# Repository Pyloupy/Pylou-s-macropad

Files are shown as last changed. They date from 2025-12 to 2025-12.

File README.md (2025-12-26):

# Pylou-s-macropad
A custom macropad for the awesome project hackpad! Using a screen 4 keys a knob and a bunch of LEDs, i'll try to develop a custom firmware with KMK to configure a bunch of things (that doesn't mean anything yet) from your PC!

## CAD
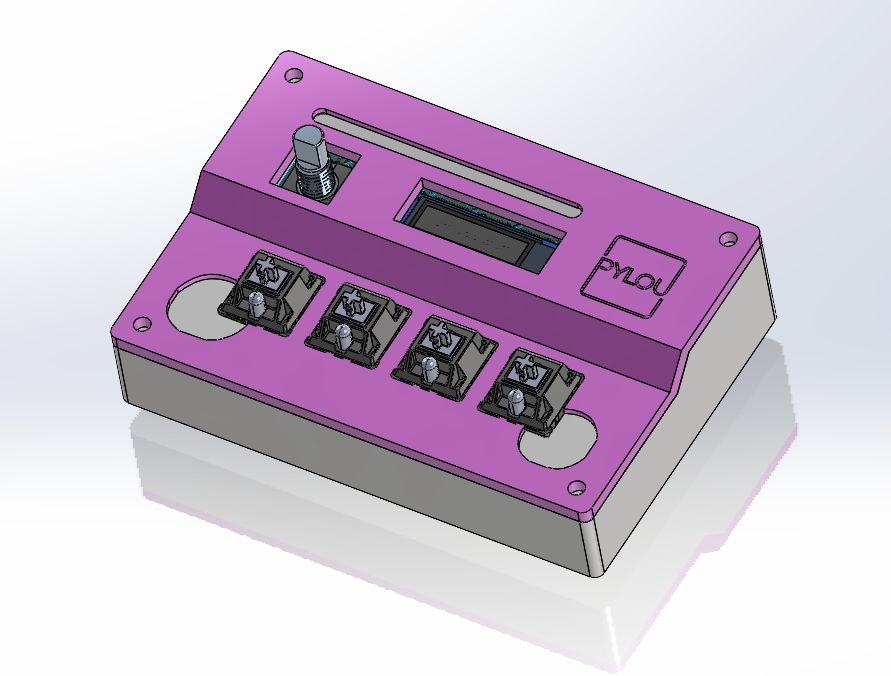
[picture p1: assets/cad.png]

My beautiful Case for this keyboard :). top and bot part fits together with simple M3 screws and heatset inserts and all 4 corners and one screw for the pcb. (I didn't add extra photos to show how it'll fit because its='s pretty self explanatory)

There's also diffuser that'll be simple 1-2mm plane of white PLA, they'll be glued to the top part!

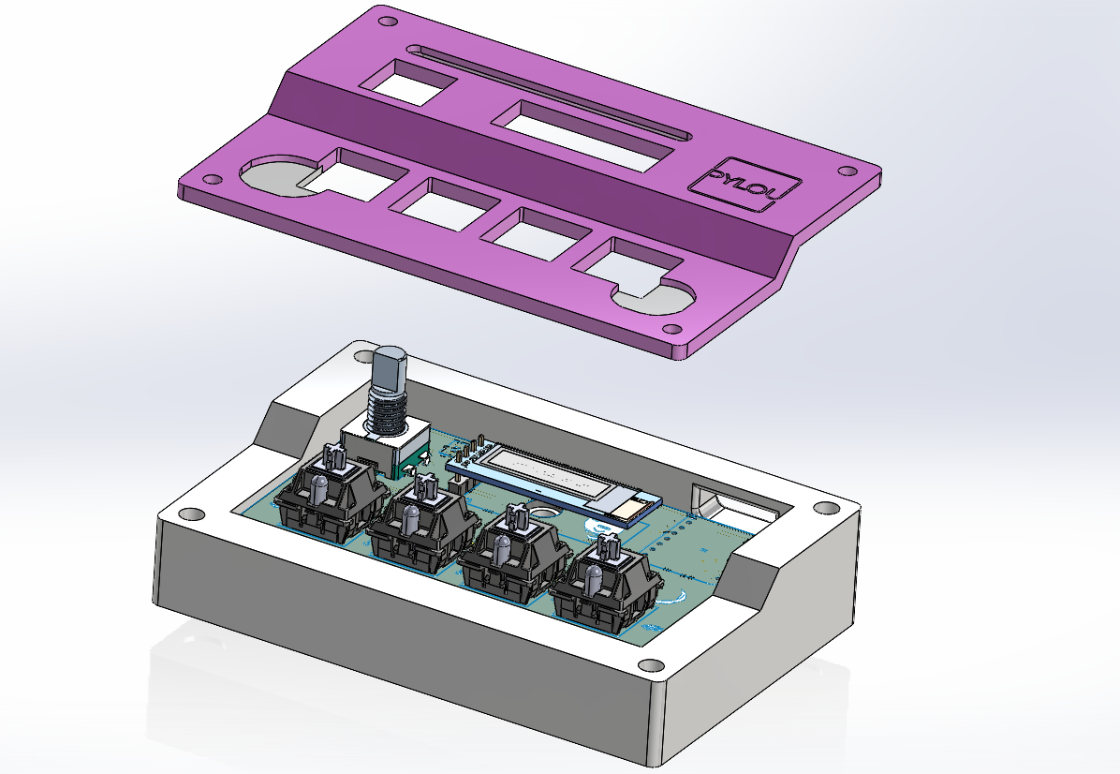
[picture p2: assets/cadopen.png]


Made with SOLIDWORKS (superior to Fusion360 :)) and it's the first time im designing a piece with it (in the past i was using blender for 3d printing ;-;), I hope it works!

## PCB
I used KiCad (for the first time) and i tried to make a compact and clean pcb with small reference and private jokes with my friends!

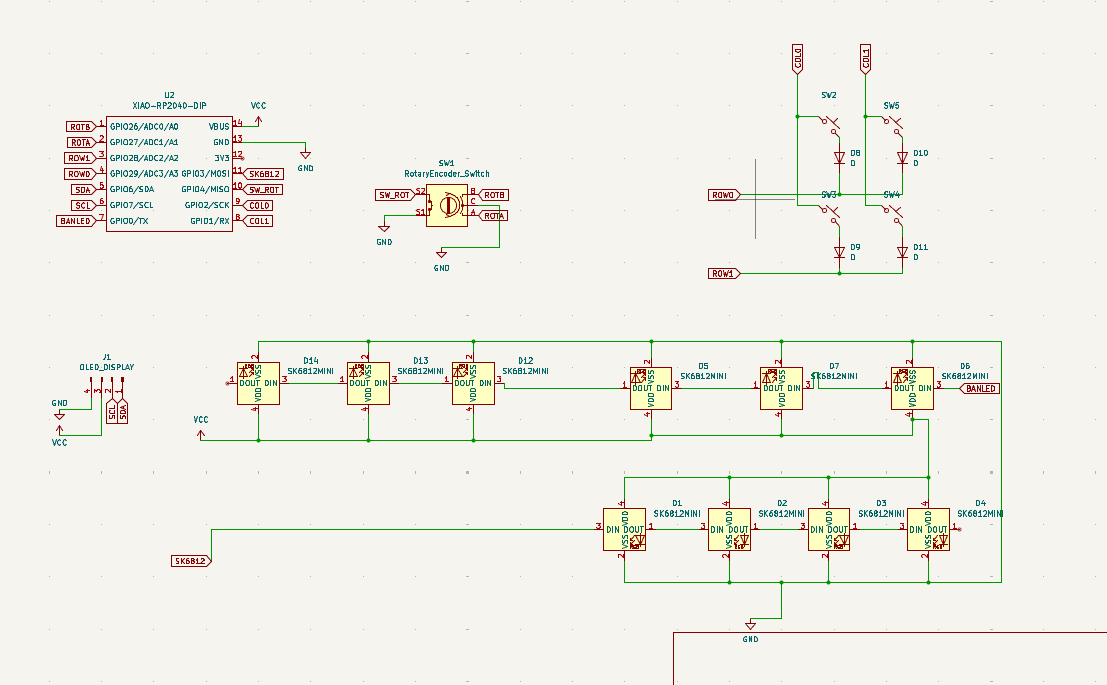
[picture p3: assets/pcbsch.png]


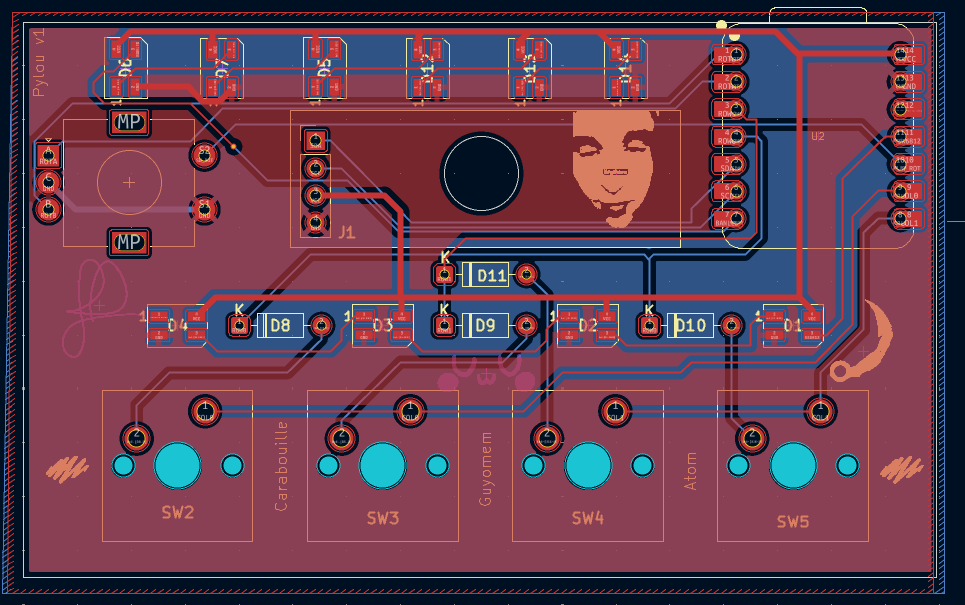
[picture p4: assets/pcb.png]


## Firmware
Made in KMK by reading docs, tutorials from [this guy](https://www.youtube.com/watch?v=PKTRkv8d0NU&list=PLtl-yze0Zzkm5n2ajJRUL48EyCyUgsXf6) (he's great) and a bit of gemini.

It's pretty simple for the moment, but i plan on addings multiples features to configure what keys does what (from your pc), change whats on the screen, show the time, rgb modes etc when i'll build the pad. I'll update the code when everything will be done! 

## BOM
Here's the list of parts for my project!

 - 1x Seeed XIAO RP2040
 - 4x Through-hole 1N4148 Diodes
 - 4x MX-Style switches
 - 1x EC11 Rotary encoders
 - 1x 0.91 inch OLED displays
 - 4x Blank DSA keycaps (White)
 - 10x SK6812 MINI-E LEDs
 - 5x M3x16mm screws
 - 5x M3x5mx4mm heatset inserts
 - 1x 3D printed case: top pink and the rest white

## Special Thanks!
My appreciation to the opheuspad project wich helped me many times! and to the hacklab community very responsive and kind!

PS: I'm french, so forgive me for any english syntax errors :)

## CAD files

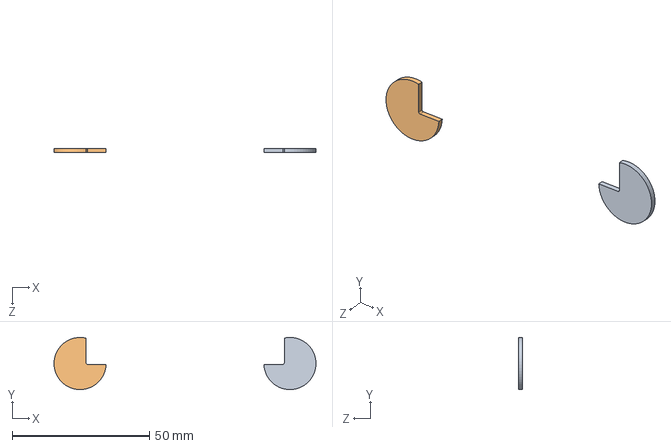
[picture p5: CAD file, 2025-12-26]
production/round diffuser near keys.STEP
95.5 x 19.0 x 1.60 mm

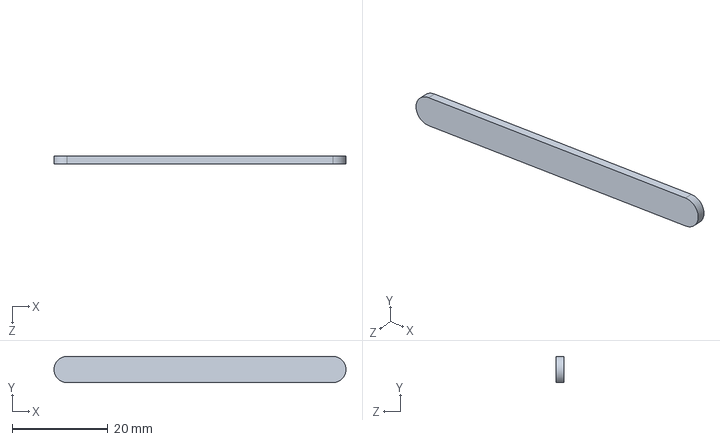
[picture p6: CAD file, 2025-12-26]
production/diffuser for led strip.STEP
61.0 x 5.50 x 1.60 mm

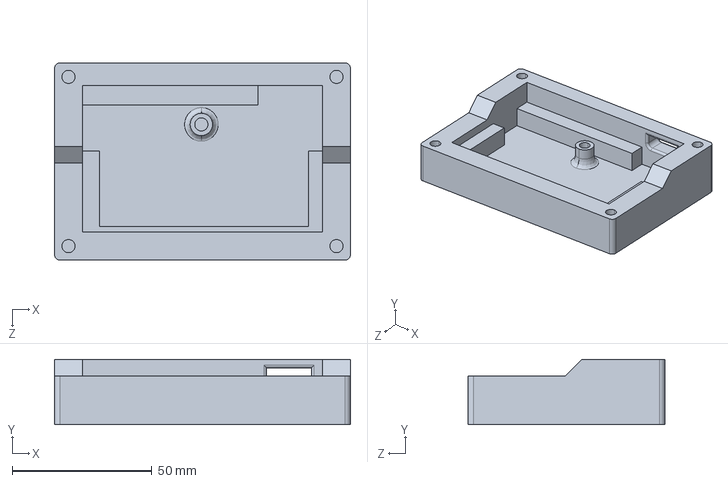
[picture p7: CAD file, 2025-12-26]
production/bottom.STEP
105.8 x 23.3 x 70.5 mm

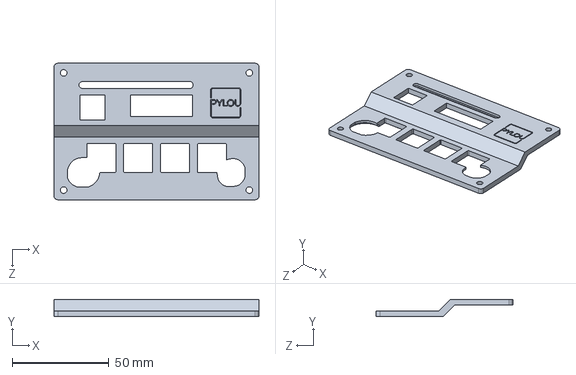
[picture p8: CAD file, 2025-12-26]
production/top.STEP
105.8 x 9.00 x 70.5 mm

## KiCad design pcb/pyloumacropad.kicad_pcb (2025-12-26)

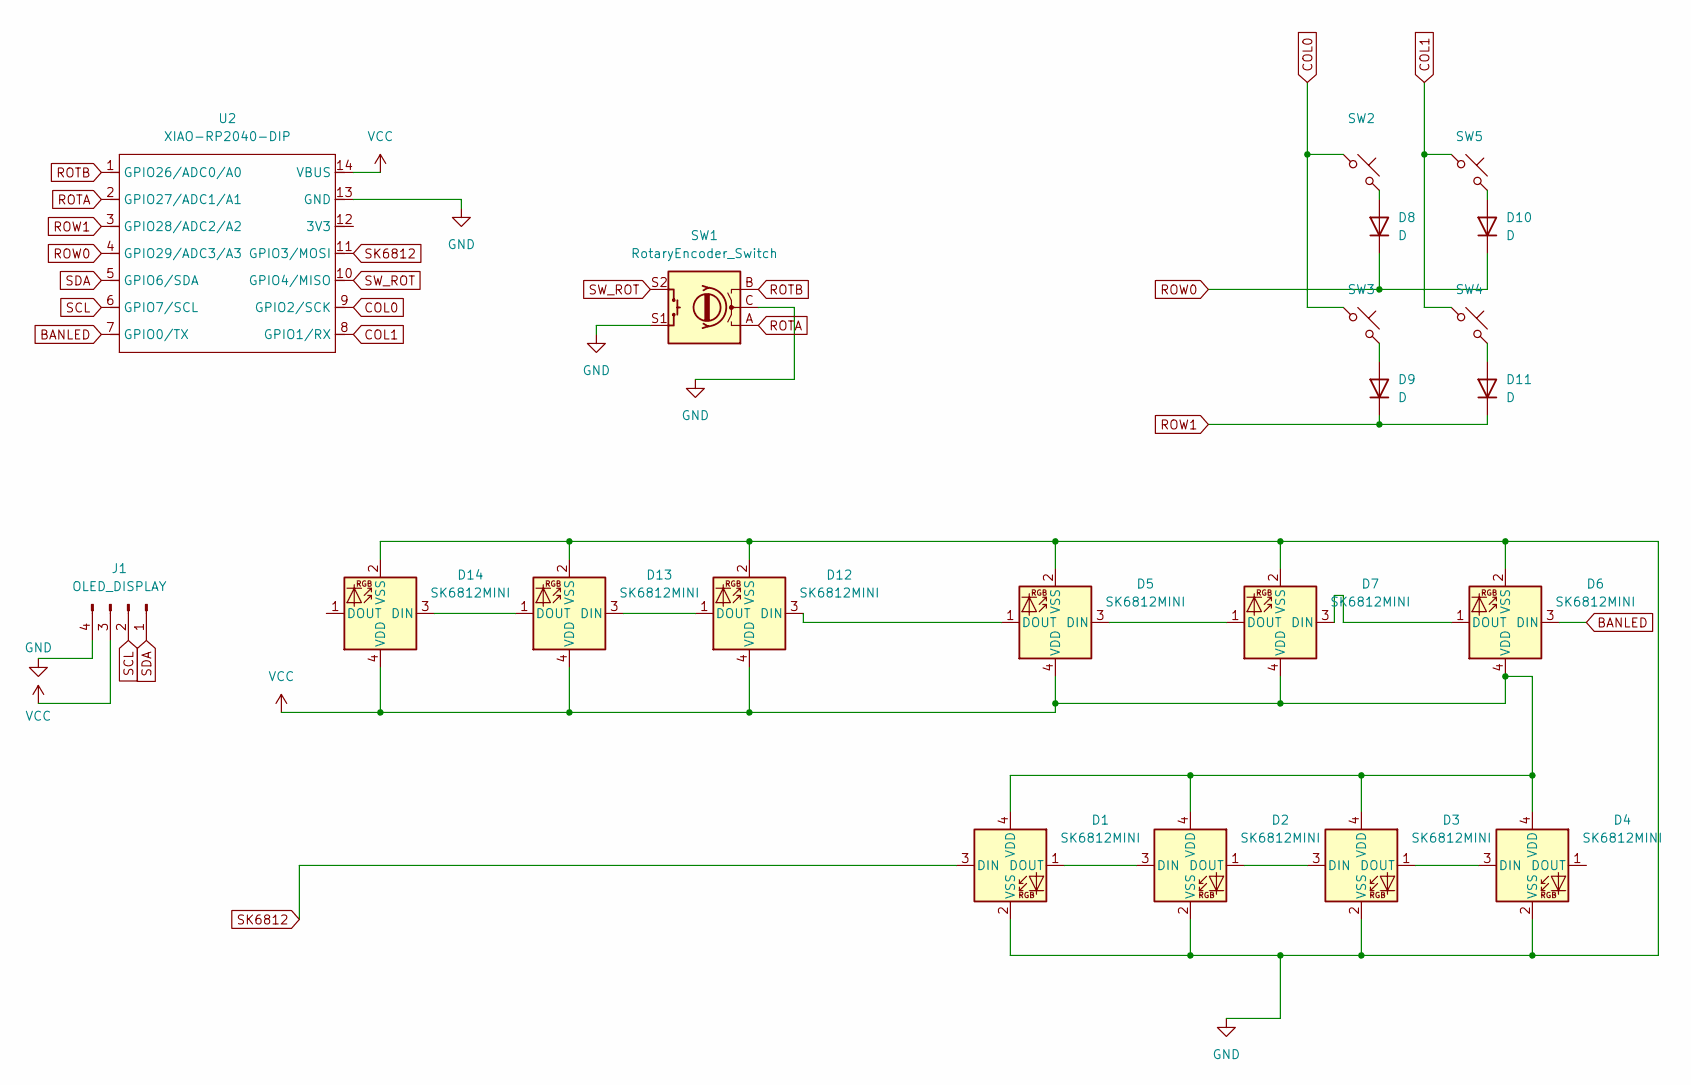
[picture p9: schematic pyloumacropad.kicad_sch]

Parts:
D1, D2, D3, D4, D5, D6, D7, D12, D13, D14: SK6812MINI; LED_SK6812MINI_PLCC4_3.5x3.5mm_P1.75mm
D8, D9, D10, D11: D; D_DO-35_SOD27_P7.62mm_Horizontal
J1: OLED_DISPLAY; PinHeader_1x04_P2.54mm_Vertical
SW1: RotaryEncoder_Switch; RotaryEncoder_Alps_EC11E-Switch_Vertical_H20mm
SW2, SW3, SW4, SW5: SW_Push_45deg; SW_Cherry_MX_1.00u_PCB
U2: XIAO-RP2040-DIP

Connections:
BANLED: D6.3 (DIN), U2.7 (GPIO0/TX)
COL0: SW2.1, SW3.1, U2.9 (GPIO2/SCK)
COL1: SW4.1, SW5.1, U2.8 (GPIO1/RX)
GND: D1.2 (VSS), D2.2 (VSS), D3.2 (VSS), D4.2 (VSS), D5.2 (VSS), D6.2 (VSS), D7.2 (VSS), D12.2 (VSS), D13.2 (VSS), D14.2 (VSS), J1.4, SW1.C, SW1.S1, U2.13 (GND)
unnamed: D1.1 (DOUT), D2.3 (DIN)
unnamed: D2.1 (DOUT), D3.3 (DIN)
unnamed: D3.1 (DOUT), D4.3 (DIN)
unnamed: D5.3 (DIN), D7.1 (DOUT)
unnamed: D6.1 (DOUT), D7.3 (DIN)
unnamed: D8.2 (A), SW2.2
unnamed: D9.2 (A), SW3.2
unnamed: D10.2 (A), SW5.2
unnamed: D11.2 (A), SW4.2
unnamed: D5.1 (DOUT), D12.3 (DIN)
unnamed: D12.1 (DOUT), D13.3 (DIN)
unnamed: D13.1 (DOUT), D14.3 (DIN)
ROTA: SW1.A, U2.2 (GPIO27/ADC1/A1)
ROTB: SW1.B, U2.1 (GPIO26/ADC0/A0)
ROW0: D8.1 (K), D10.1 (K), U2.4 (GPIO29/ADC3/A3)
ROW1: D9.1 (K), D11.1 (K), U2.3 (GPIO28/ADC2/A2)
SCL: J1.2, U2.6 (GPIO7/SCL)
SDA: J1.1, U2.5 (GPIO6/SDA)
SK6812: D1.3 (DIN), U2.11 (GPIO3/MOSI)
SW_ROT: SW1.S2, U2.10 (GPIO4/MISO)
VCC: D1.4 (VDD), D2.4 (VDD), D3.4 (VDD), D4.4 (VDD), D5.4 (VDD), D6.4 (VDD), D7.4 (VDD), D12.4 (VDD), D13.4 (VDD), D14.4 (VDD), J1.3, U2.14 (VBUS)

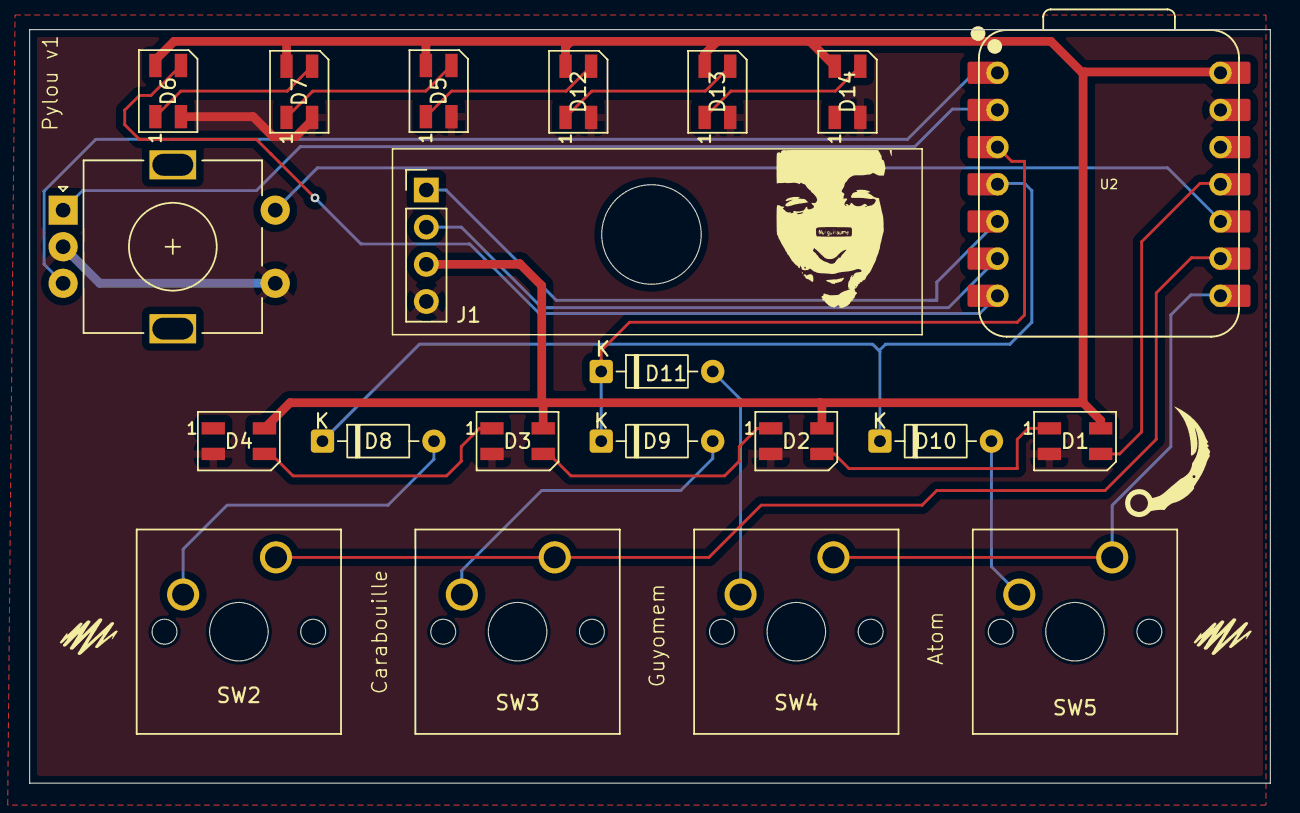
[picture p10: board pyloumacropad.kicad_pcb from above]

Board: 2 copper layers, 84.8 x 51.5 mm, 21 parts (0 on the bottom side), 25 nets.

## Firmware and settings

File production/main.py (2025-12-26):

import board
import busio

from kmk.kmk_keyboard import KMKKeyboard
from kmk.keys import KC, make_key
from kmk.scanners import DiodeOrientation
from kmk.modules.layers import Layers
from kmk.modules.encoder import EncoderHandler
from kmk.modules.combos import Combos, Chord
from kmk.extensions.display import Display, ImageEntry, TextEntry
from kmk.extensions.display.ssd1306 import SSD1306
from kmk.extensions.rgb import RGB
from kmk.extensions.media_keys import MediaKeys

# Setup initialisation
keyboard = KMKKeyboard()

#2x2 Matrix, useless here but i wated to give it a shot!
keyboard.col_pins = (board.D8, board.D7)
keyboard.row_pins = (board.D3, board.D2)
keyboard.diode_orientation = DiodeOrientation.COL2ROW

# strip of rgb for pure decoration
rgb_strip = RGB(
    pixel_pin=board.D6,
    num_pixels=6,
    animation_mode="rainbow"
)
keyboard.extensions.append(rgb_strip)

# leds on the keys
rgb_keys = RGB(
    pixel_pin=board.D10,
    num_pixels=4,
    animation_mode="reactive"
)
keyboard.extensions.append(rgb_keys)

# --- LAYERS & STATE for configurations ---
layers = Layers()
keyboard.modules.append(layers)

class State:
    current_profile = 0
    total_profiles = 5

state = State()

def change_profile(direction):
    if direction == "NEXT":
        state.current_profile = (state.current_profile + 1) % state.total_profiles
    elif direction == "PREV":
        state.current_profile = (state.current_profile - 1) % state.total_profiles

    keyboard.tap_key(KC.DF(state.current_profile))

KC_PROF_NEXT = make_key(on_press=lambda *args: change_profile("NEXT"))
KC_PROF_PREV = make_key(on_press=lambda *args: change_profile("PREV"))

# --- SCREEN ---
i2c_bus = busio.I2C(board.D5, board.D4)
driver = SSD1306(i2c=i2c_bus, device_address=0x3C)
display = Display(display=driver, width=128, height=32, brightness=1)
keyboard.extensions.append(display)

def draw_top_bar(display):
    for i in range(5):
        x = 10 + (i * 22)
        filled = 1 if i == state.current_profile else 0
        display.rect(x, 0, 15, 6, 1, filled=filled)

display.entries = [
    ImageEntry(image=draw_top_bar, x=0, y=0),
    TextEntry(text="Pylou", x=64, y=20, x_anchor='M', y_anchor='M'),
]

# --- KEYMAP ---
my_keymap = [[KC.A, KC.B, KC.C, KC.D], [KC.TRNS] * 4, [KC.TRNS] * 4, [KC.TRNS] * 4, [KC.TRNS] * 4]

my_keymap.append([
    KC.RGB_MOD,
    KC.RGB_ANI,
    KC.RGB_AND,
    KC.RGB_TOG
])
keyboard.keymap = my_keymap

# --- MEDIA KEYS ---
keyboard.extensions.append(MediaKeys())

# --- ENCODER ---
encoder_handler = EncoderHandler()
keyboard.modules.append(encoder_handler)
encoder_handler.pins = ((board.D1, board.D0, board.D9),)

encoder_map = [((KC.VOLD, KC.VOLU, KC.MPLY),)] * 5
encoder_map.append(((KC_PROF_PREV, KC_PROF_NEXT, KC.MPLY),))
encoder_handler.map = encoder_map

# --- COMBOS to switch configurations ---
combos = Combos()
keyboard.modules.append(combos)
LAYER_CONTROL = 5
combos.combos = [Chord((my_keymap[0][0], my_keymap[0][1]), KC.MO(LAYER_CONTROL))]

if __name__ == '__main__':
    keyboard.go()
